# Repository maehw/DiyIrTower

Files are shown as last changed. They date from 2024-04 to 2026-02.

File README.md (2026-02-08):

# README

Can be used as a replacement of the original LEGO IR serial tower with programs and platforms such as

* [WebPBrick](https://www.webpbrick.com): web-based NQC IDE (see also: [github.com/maehw/WebPBrick/](https://github.com/maehw/WebPBrick/))
* [Bricx Command Center (BricxCC)](https://bricxcc.sourceforge.net/): 32-bit Windows IDE
* `firmdl3` command line download tool
* probably other software

to **load user programs and firmware** on the yellow LEGO Mindstorms RCX programmable brick.

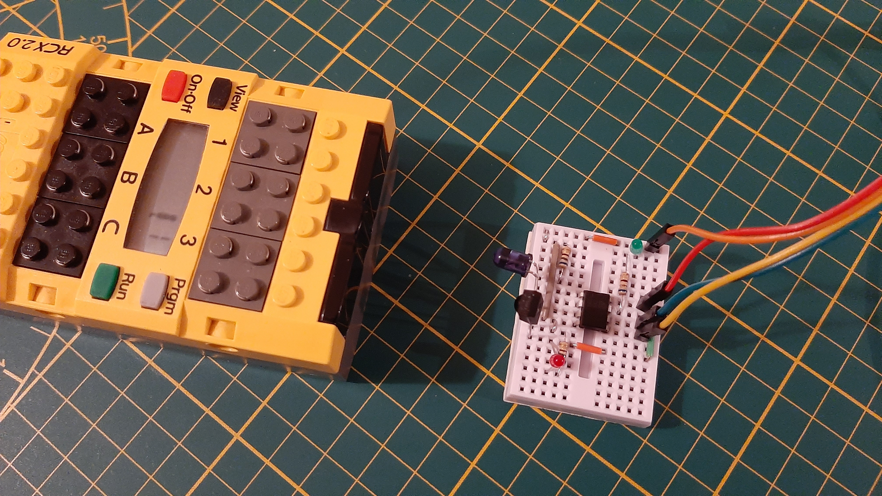
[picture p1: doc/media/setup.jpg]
RCX firmware download setup


## Hardware

> ⚠️ **Warning**: Exposure to infrared light can cause harm to humans. Prolonged or intense exposure may lead to damage to the eyes or skin. Always use proper safety equipment when working with infrared light sources. Make sure to limit the current through the infrared TX LED!

### Pin Assignment

At the heart of the DIY solution, there's an 8-pin ATtiny13A microcontroller.

Pin Assignment Table for the ATtiny13A:

| IC Pin | Pin | Purpose | Direction | Side of IC | ISP Usage |
|---|---|---|---|---|---|
| 1 | PB5 | Reset | Unused | Left | Reset |
| 2 | PB3 | IR_LED_TX_PIN | Output | Left | |
| 3 | PB4 | PHOTO_RX_PIN | Input | Left | |
| 4 | GND | Ground | - | Left | GND |
| 5 | PB0 | UART_RX_PIN | Output | Right | MOSI |
| 6 | PB1 | UART_TX_PIN | Input | Right | MISO |
| 7 | PB2 | IR_ACTIVITY_LED_PIN  | Output | Right | SCK |
| 8 | VCC | Supply Voltage (VCC) | - | Right | VCC |

The column "ISP Usage" shows what pins need to be connected for programming ("flashing") by a 6-pin AVR _In-System Programmer_ (ISP).

### Hardware Parts

- ATtiny13A microcontroller as the "brain" (calibrated internal 9.6 MHz oscillator as clock source; other uCs such as the ATtiny85 _may_ work as they have more SRAM and more flash memory, but timing values will need to be adjusted)
- Vishay Semiconductors TSOP4338 or TSOP4838 38 kHz infrared receiver (others 38 kHz infrared receivers _may_ work)
- Vishay Semiconductors TSAL6200 940 nm infrared TX LED (others 940 nm infrared TX LEDs _may_ work)

If you've built a working DiyIrTower yourself with these or different parts, please let me know! The first design has used the TSOP4338. As it's not available everywhere, it has also been tested to work with the TSOP4838.

In my case, the circuitry is powered by a USB/serial converter cable which is also used to transfer the data over a virtual COM port (USB CDC interface). Please note that the converter cable of choice uses TTL voltage levels and not RS-232!

### Classic Breadboard

For the breadboard version see the image at the top. The Fritzing breadboard diagram looks as follows (please also pay attention to the hints inside the image):

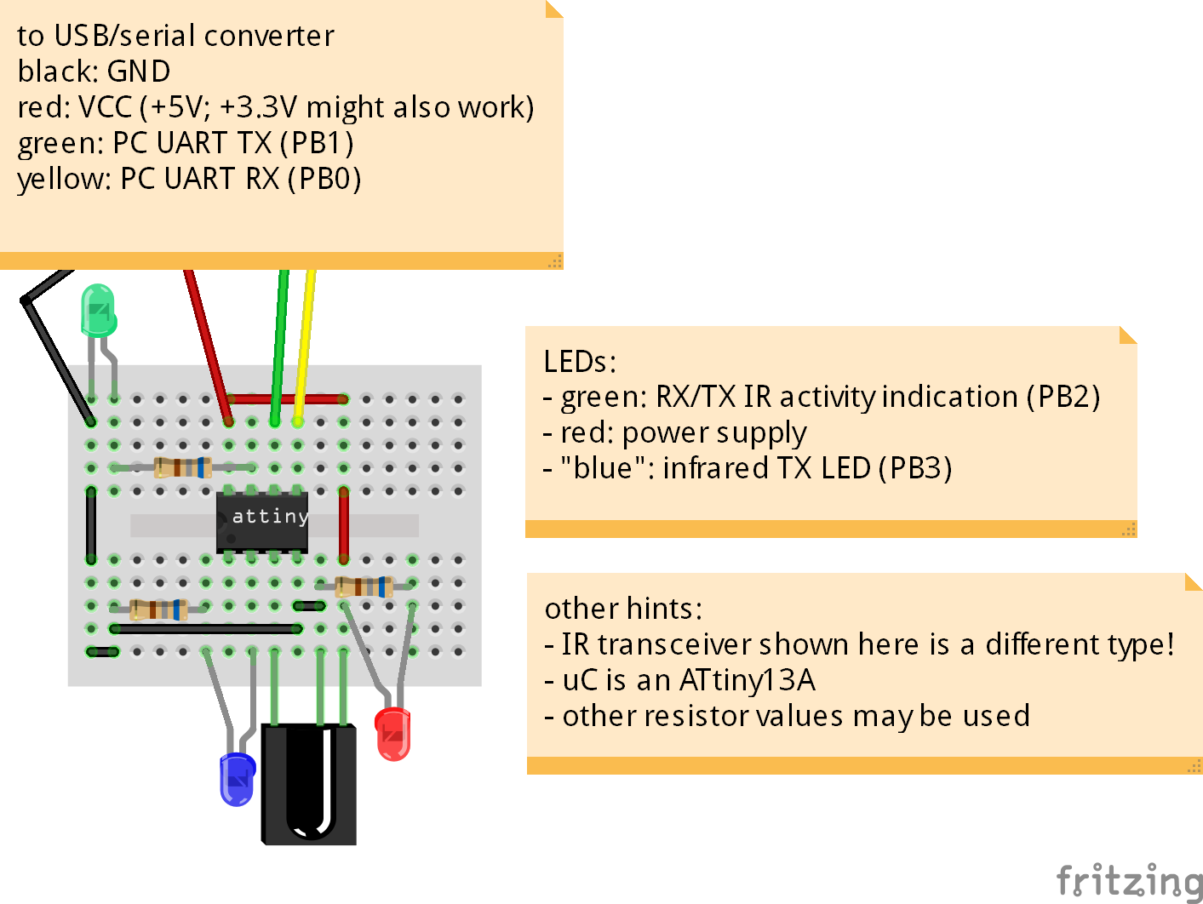
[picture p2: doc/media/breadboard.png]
Fritzing breadboard diagram


### Solder Breadboard

An alternative would be a solder breadboard to make something semi-permanent (the green activity LED is hidden in the next photo between the jumper wires of the USB/serial converter cable):

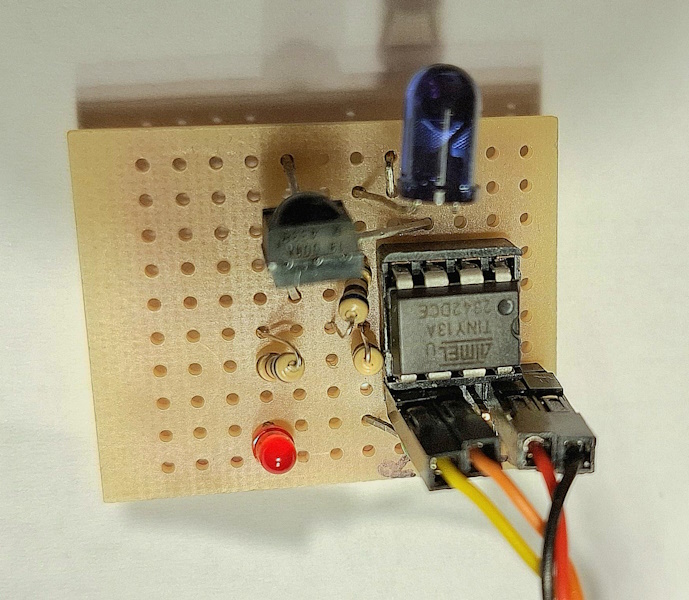
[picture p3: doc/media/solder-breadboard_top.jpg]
Solder breadboard top


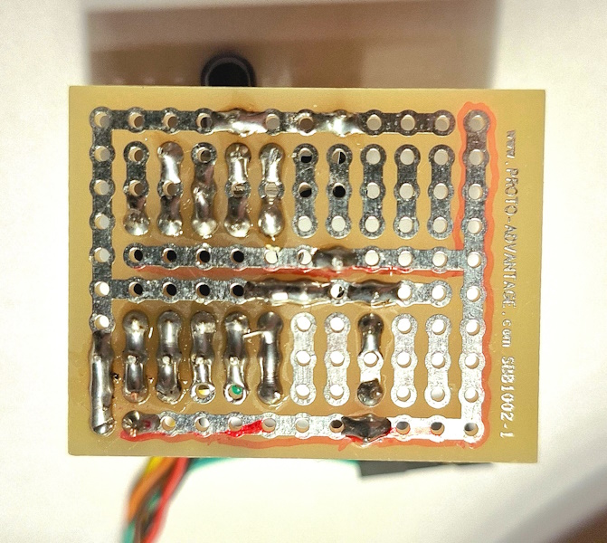
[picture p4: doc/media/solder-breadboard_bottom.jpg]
Solder breadboard bottom


### CAD PCB with KiCAD

Since January 2026, there's a KiCAD project with all necessary files (i.e. schematic, PCB layout, pre-generated Gerber files). So instead of putting the components together on a breadboard, a PCB can be ordered. At the time of writing, some prototype PCBs (Rev. 1.0) have been ordered. But I cannot guarantee, that the design is free of bugs.

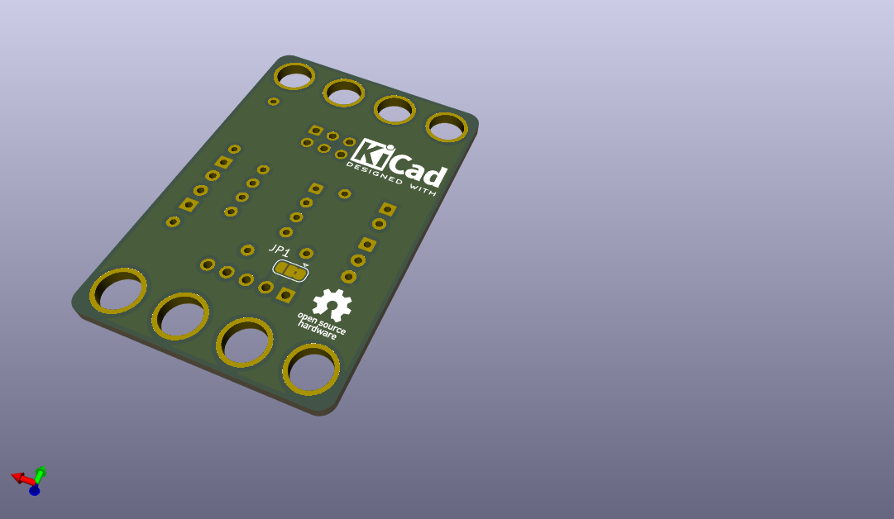
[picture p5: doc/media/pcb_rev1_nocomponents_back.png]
PCB (front) without components


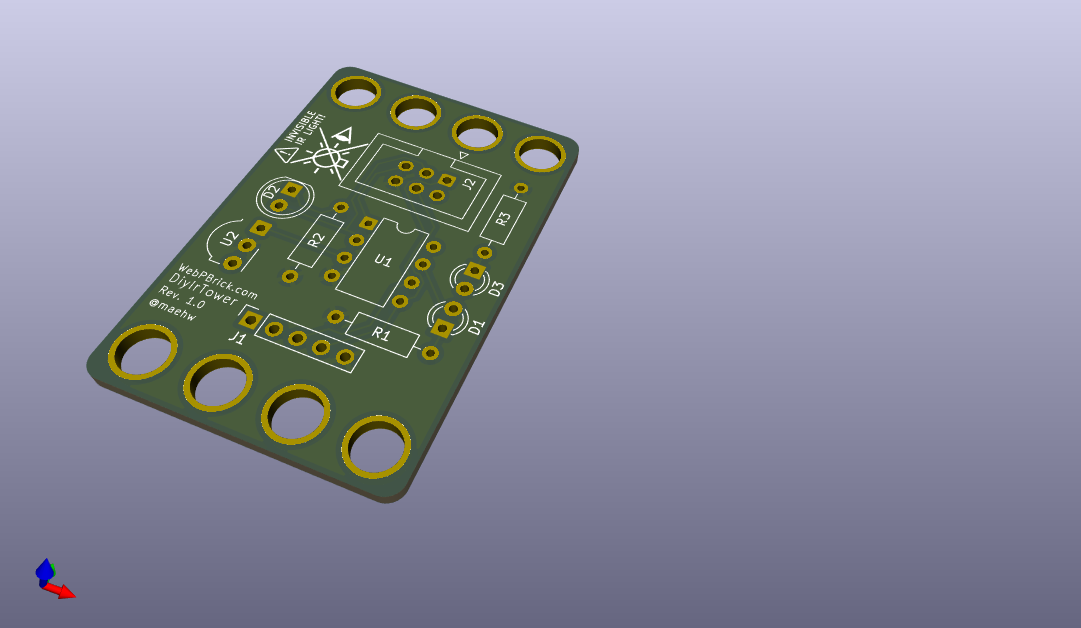
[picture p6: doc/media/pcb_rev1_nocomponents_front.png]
PCB (back) without components


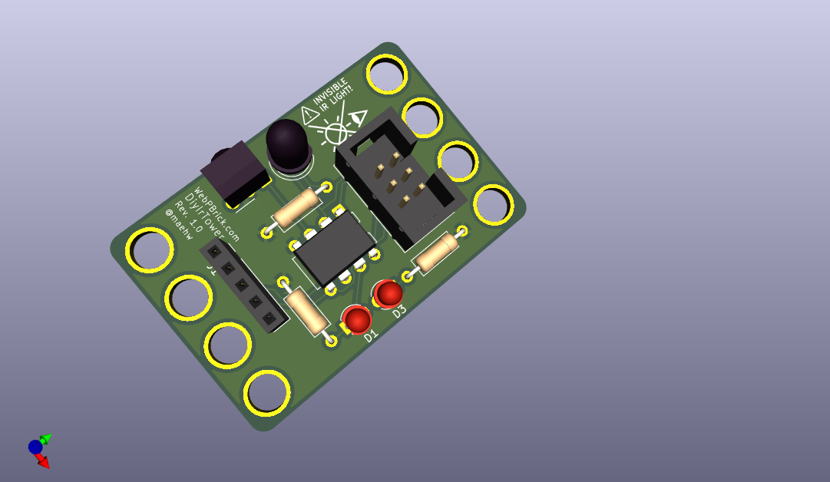
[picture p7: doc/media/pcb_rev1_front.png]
PCB (front) with THT components


I've decided to keep through-hole components, as they are easier to solder for beginners. It may make sense to add a DIP8 IC socket for the uC. The power and activity LEDs (and their resistors) are optional, as is the ISP header for initially flashing the IC. So a setup with the minimum of components would look like this:

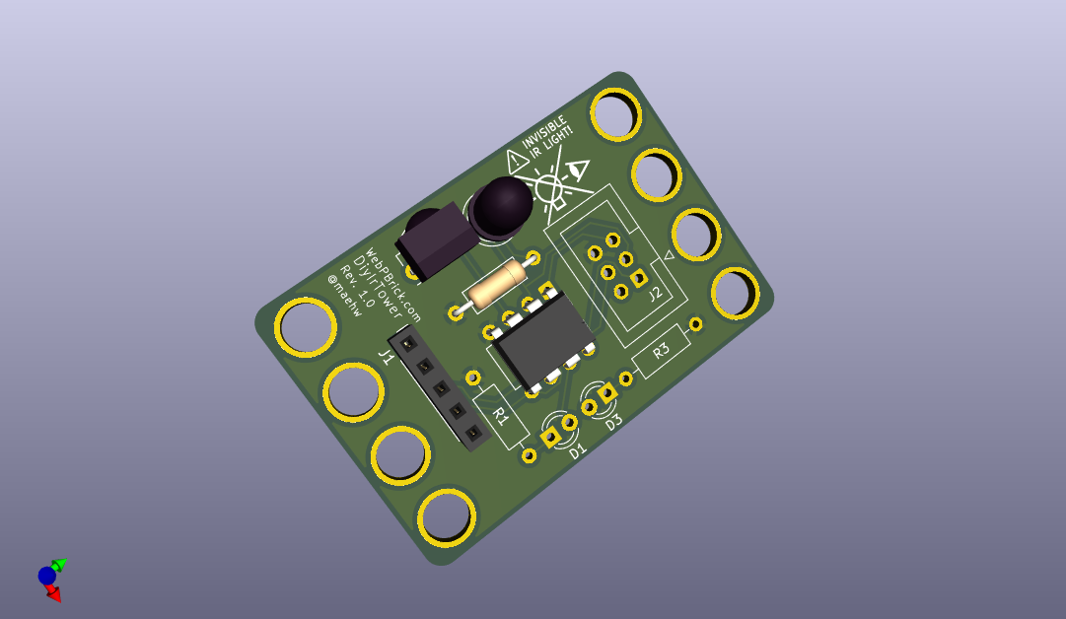
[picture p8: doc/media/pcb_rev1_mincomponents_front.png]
PCB (front) with minimum of THT components


By the way, I'd choose a rectangular connector for J1. Also, you'll have to bend the TX photo diode D2 sideways, so that it points to the same side as the IR receiver IC.

## Firmware

Find the productive firmware in folder `./firmware`.

### Prerequisites

- GNU C cross-compiler for AVR 8-bit `gcc-avr` (other build toolchains *may* work as well)
- `avrdude`: program for downloading and uploading the on-chip memories of AVR microcontrollers (or another similar tool)

### Build

To build, run:

```shell
avr-gcc -g -Wall -Os -mmcu=attiny13a -o main.elf main.c
```

_(Append the verbosity flag `-v` to see what's going on behind the scenes.)_

Want to check if it will it fit into the internal flash?

```shell
avr-size main.elf
   text	   data	    bss	    dec	    hex	filename
    776	      0	      7	    783	    30f	main.elf
```

Make sure to burn the microcontrollers fuses so that

- the calibrated internal 9.6 MHz oscillator is selected
- clock pre-scaler set to 1 (device is shipped with CKDIV8 programmed).

Reading fuses with avrdude (and in this case an `ehajo-isp` in-system programmer):

```shell
avrdude -c ehajo-isp -p t13a -U hfuse:r:-:h -U lfuse:r:-:h
```

The default values for the two fuse bytes of the ATtiny13A are `0xff` (high), `0x6a` (low).  The required settings however are: `0xff` (high), `0x7a` (low). Writing fuses with avrdude:

```shell
avrdude -c ehajo-isp -p t13a -U hfuse:w:0xff:m -U lfuse:w:0x7a:m
```

_(Hint: If the `avrdude` version being used gives *"avrdude: AVR Part "t13a" not found."*, try using `t13` instead of `t13a`.)_

Finally, flash the firmware:

```shell
avrdude -c ehajo-isp -p t13a -U flash:w:main.elf:e
```

### Test firmware

Please note that under `./test/firmware`, there are some more code files to test the assembled hardware. The commands from above can be reused, only the filename needs to be changed.

`blink.c` will blink the activity indication LED and hence allow to check if the LED is working and the compilation and flashing mechanisms also work.

`pulsed_ir_tx.c` will blink the activity indication LED and also transmit modulated infrared light at 38 kHz for 0.5 seconds and then switch the transmitter off for another 0.5 seconds. This allows to check if the fuse bytes have been set correctly or the blinking is way slower and the default `CKDIV8` may not have been overwritten.

`serial_echo.c` will _echo_ the serially received UART characters. Please note that this example does not make use of any uC UART peripheral but only relies upon GPIO pin edge detection on the "UART" receive pin. This can be used with any terminal emulator that works with serial devices or with the Python script `/test/scripts/serial_coms.py` to send and receive binary data:

```shell
$ python serial_coms.py -h
usage: serial_coms.py [-h] serial_device data_to_send

Send binary data over serial and receive response.

positional arguments:
  serial_device  Name of the serial device (e.g., '/dev/ttyUSB0')
  data_to_send   Binary data to send in HEX format (e.g., '55FF00609F609F')

options:
  -h, --help     show this help message and exit
```

Example:

```shell
$ python serial_coms.py /dev/ttyUSB0 11223344
[TX] 11 22 33 44 
[RX] 11 22 33 44
```

The same four bytes should be received that also have been transmitted before - just as you'd expect from an echo application! Check the command line output!

## Design details

The following timing diagram shows four signals from top to bottom:

* `UART_TX_PIN`: the UART transmit (=TX) signal - as sent by the PC, coming from the attached USB/serial converter
* `IR_LED_TX_PIN`: the modulated infrared transmit signal on the IR TX LED, on–off keying (OOK) modulated at 38 kHz, 38 kHz carrier is _active_ during _low_ periods of `UART_TX_PIN`
* `PHOTO_RX_PIN`: the signal on the (already demodulated) infrared receiver
* `UART_RX_PIN`: the UART receive (=RX) signal - as sent by the DIY IR tower to the USB/serial converter

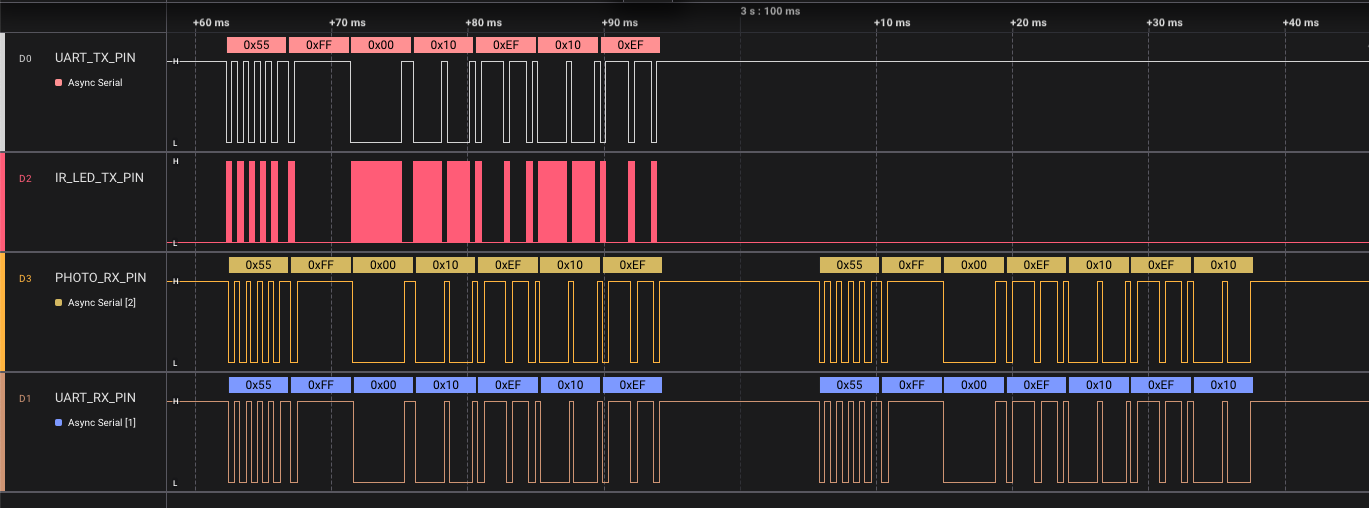
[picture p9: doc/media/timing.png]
Timing diagram


The diagram shows the message `0x55 0xFF 0x00 0x10 0xEF 0x10 0xEF` being sent from the PC to the RCX (left half). It also shows the response from the RCX to the PC: `0x55 0xFF 0x00 0xEF 0x10 0xEF 0x10` (right half).

In the left half one can also see that the signal transmitted by the DIY IR tower is reflected and directly received by itself. This is due to the arrangement of IR TX LED and IR receiver - and afair can also be seen with the original IR towers. This "echo effect" must/can be handled in software!

Zooming in (less time for the same screen width) reveals the delays between the signals:

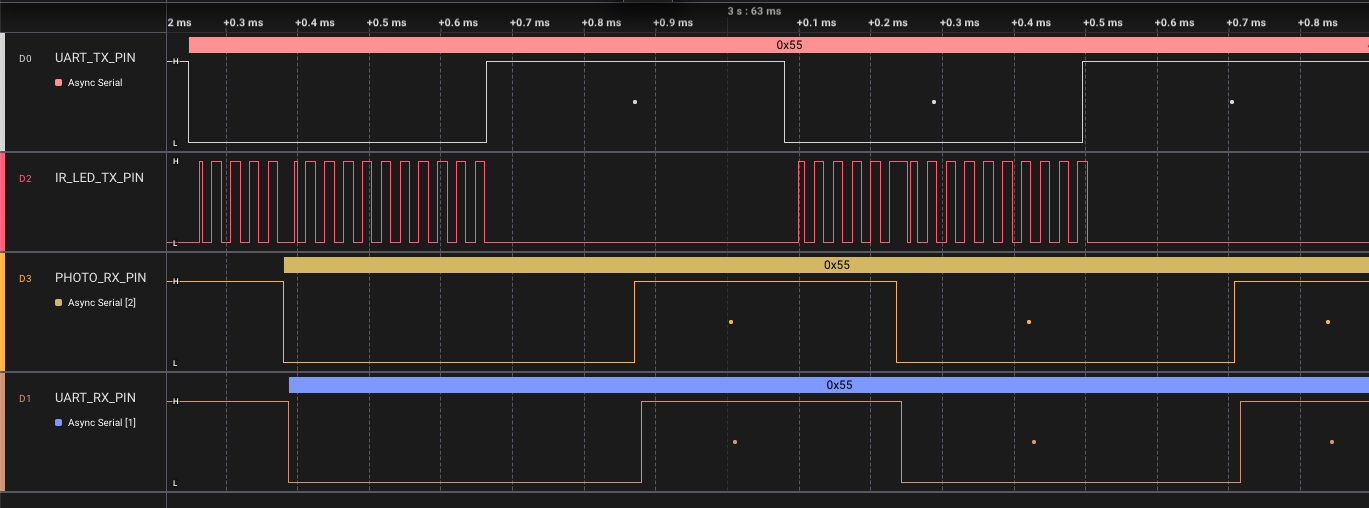
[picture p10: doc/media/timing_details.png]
Timing diagram with details


## Disclaimer

LEGO® is a trademark of the LEGO Group of companies which does not sponsor, authorize or endorse this project.

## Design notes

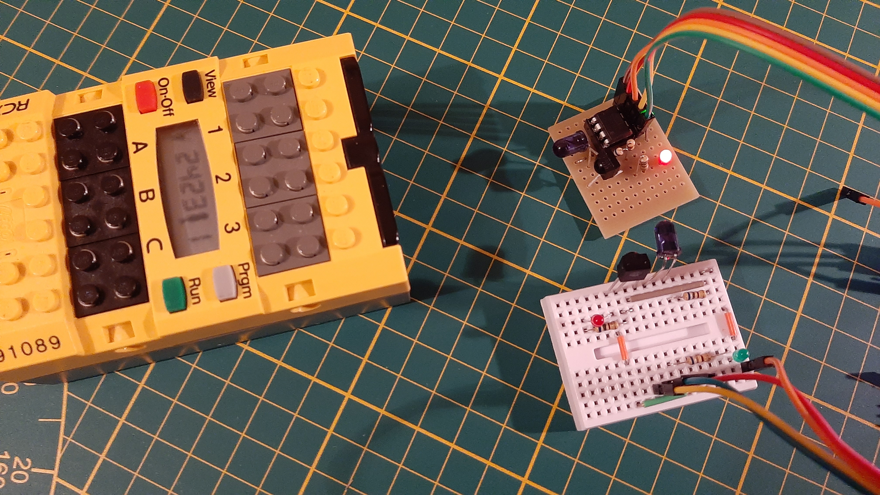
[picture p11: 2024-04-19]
doc/media/firmware-download.jpg

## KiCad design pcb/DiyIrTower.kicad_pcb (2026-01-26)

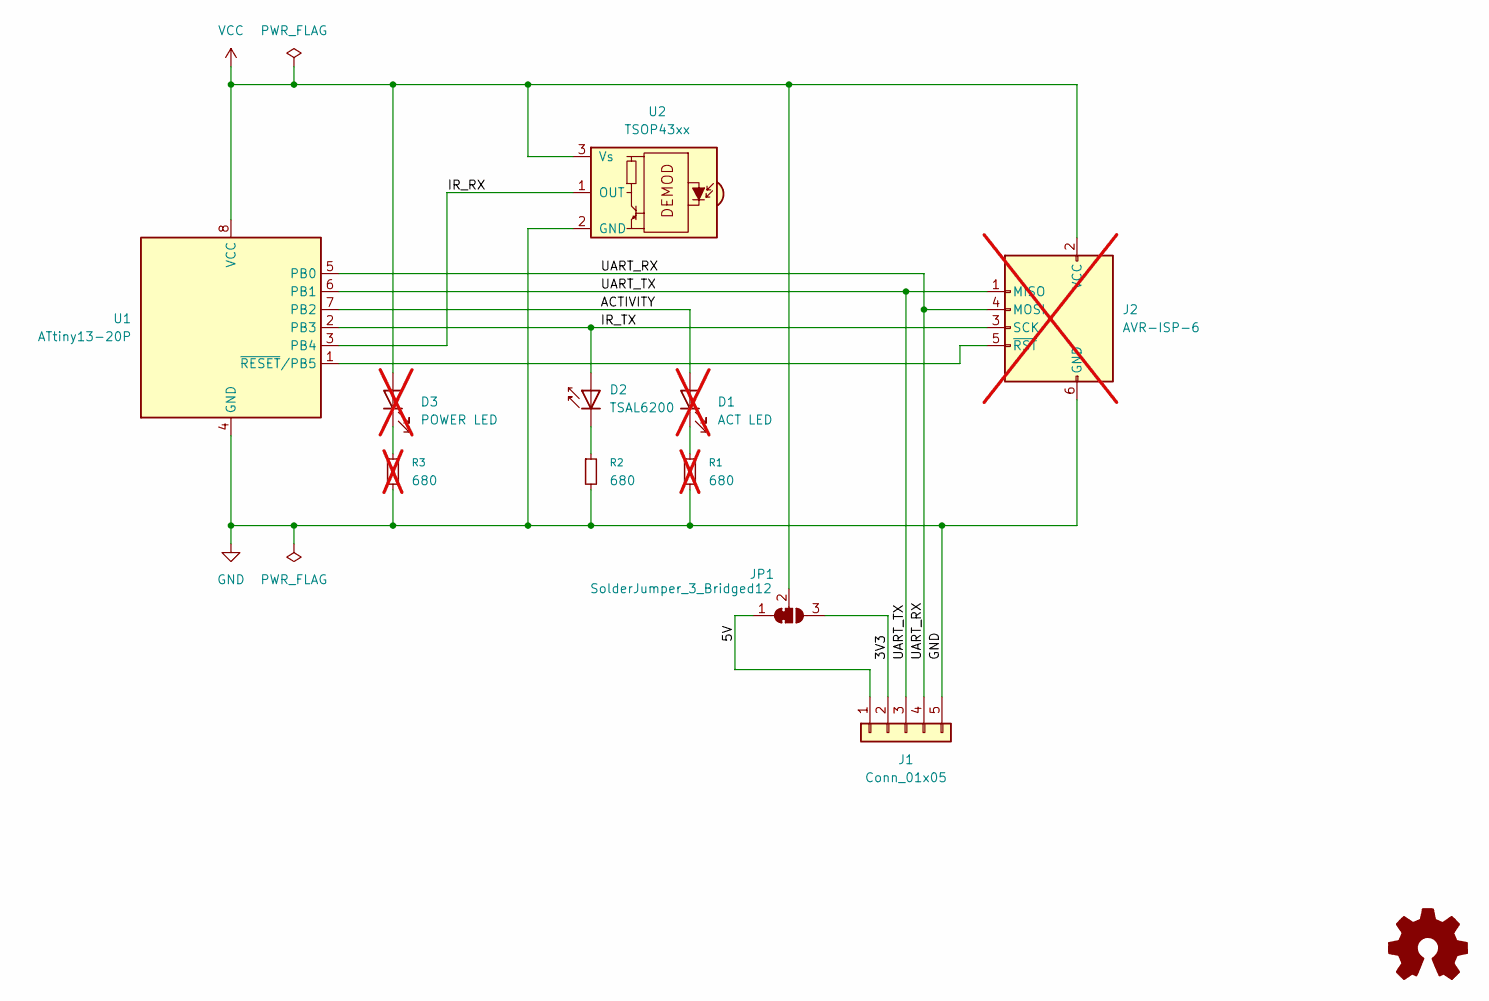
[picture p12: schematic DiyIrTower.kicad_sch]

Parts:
D1: ACT LED; LED_D3.0mm; not fitted
D2: TSAL6200; LED_D5.0mm_IRBlue
D3: POWER LED; LED_D3.0mm; not fitted
J1: Conn_01x05; PinSocket_1x05_P2.54mm_Vertical
J2: AVR-ISP-6; IDC-Header_2x03_P2.54mm_Vertical; not fitted
JP1: SolderJumper_3_Bridged12; SolderJumper-3_P1.3mm_Bridged2Bar12_RoundedPad1.0x1.5mm
R1, R3: 680; R_Axial_DIN0207_L6.3mm_D2.5mm_P10.16mm_Horizontal; not fitted
R2: 680; R_Axial_DIN0207_L6.3mm_D2.5mm_P10.16mm_Horizontal
U1: ATtiny13-20P; DIP-8_W7.62mm
U2: TSOP43xx; Vishay_MOLD-3Pin

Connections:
/3V3: J1.2, JP1.3 (B)
/5V: J1.1, JP1.1 (A)
/ACTIVITY: D1.2 (A), U1.7 (PB2)
/IR_RX: U1.3 (PB4), U2.1 (OUT)
/IR_TX: D2.2 (A), J2.3 (SCK), U1.2 (PB3)
/UART_RX: J1.4, J2.4 (MOSI), U1.5 (PB0)
/UART_TX: J1.3, J2.1 (MISO), U1.6 (PB1)
GND: J1.5, J2.6 (GND), R1.2, R2.2, R3.2, U1.4 (GND), U2.2 (GND)
unnamed: D1.1 (K), R1.1
unnamed: D2.1 (K), R2.1
unnamed: D3.1 (K), R3.1
unnamed: J2.5 (~RST), U1.1 (~RESET/PB5)
VCC: D3.2 (A), J2.2 (VCC), JP1.2 (C), U1.8 (VCC), U2.3 (Vs)

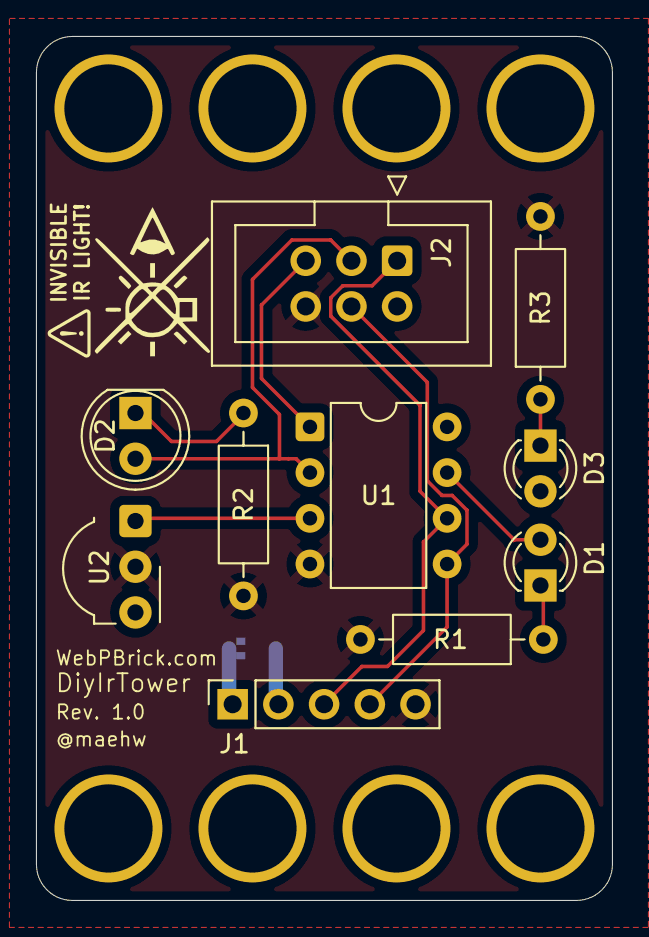
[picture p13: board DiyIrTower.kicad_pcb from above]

Board: 2 copper layers, 32.0 x 48.0 mm, 13 parts (1 on the bottom side), 13 nets.

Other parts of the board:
MH: brick-1x4
MH#2: brick-1x4

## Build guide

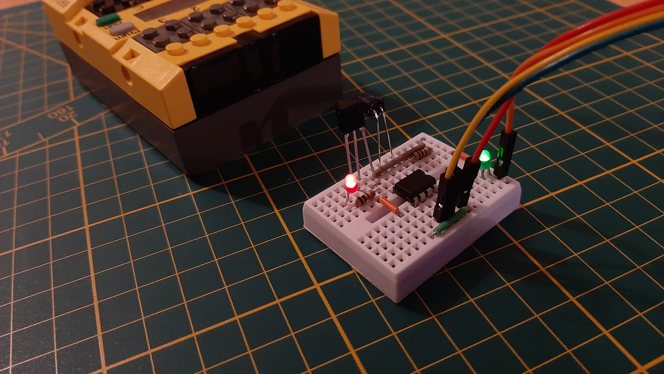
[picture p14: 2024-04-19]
doc/media/setup-side.jpg

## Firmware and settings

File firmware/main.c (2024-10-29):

/*
 * DiyIrTower
 * Copyright (C) 2024 maehw
 *
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
 * You should have received a copy of the GNU General Public License
 * along with this program.  If not, see <http://www.gnu.org/licenses/>.
 */

// This is the productive firmware.

#ifndef F_CPU
    #define F_CPU 9600000UL
#elif F_CPU != 9600000UL
    #error "F_CPU must be set to 9.6 MHz"
#endif

#include <avr/io.h>
#include <avr/interrupt.h>
#include <stdbool.h>

/*
 * Pin Assignment Table for the ATtiny13A:
 *
 * IC Pin | Pin  | Purpose               | Direction | Side of IC
 * --------------------------------------------------------------
 * 1      | PB5  | Reset                 | Unused    | Left
 * 2      | PB3  | IR_LED_TX_PIN         | Output    | Left
 * 3      | PB4  | PHOTO_RX_PIN          | Input     | Left
 * 4      | GND  | Ground                | -         | Left
 * 5      | PB0  | UART_RX_PIN           | Output    | Right
 * 6      | PB1  | UART_TX_PIN           | Input     | Right
 * 7      | PB2  | IR_ACTIVITY_LED_PIN   | Output    | Right
 * 8      | VCC  | Supply Voltage (VCC)  | -         | Right
 */

/*
 * Make sure to burn the fuses so that
 * - the calibrated internal 9.6 MHz oscillator is selected
 * - clock pre-scaler set to 1 (device is shipped with CKDIV8 programmed; which is not what we want).
 *
 * Reading fuses with avrdude (and in this case an ehajo-isp):
 *   avrdude -c ehajo-isp -p t13a -U hfuse:r:-:h -U lfuse:r:-:h
 * The default is: 0xff (high), 0x6a (low)
 *
 * The required setting is: 0xff (high), 0x7a (low)
 * Writing fuses with avrdude:
 *   avrdude -c ehajo-isp -p t13a -U hfuse:w:0xff:m -U lfuse:w:0x7a:m
 *
 * Compile and link it like this:
 *   avr-gcc -g -Wall -Os -mmcu=attiny13a -o main.elf main.c
 * Flash it:
 *   avrdude -c ehajo-isp -p t13a -U flash:w:main.elf:e
 */

#define IR_LED_TX_PIN        PB3 // GPIO output pin for IR LED
#define UART_TX_PIN          PB1 // GPIO input pin for enabling modulation
#define PHOTO_RX_PIN         PB4 // GPIO input pin for the demodulated signal from photo-transistor
#define IR_ACTIVITY_LED_PIN  PB2 // GPIO output pin for indicating IR TX modulation or IR RX signal detection from photo-transistor
#define UART_RX_PIN          PB0 // GPIO output pin that mirrors the input from the photo-transistor

#define MODULATION_FREQ                 38000 // 38 kHz
#define MODULATION_HALF_PERIOD          (F_CPU / (2 * MODULATION_FREQ)) -2 // Calculate the half period in clock cycles; make sure that we really get this to ~2*38 kHz here
// Needed to add a small correction offset determined by measurement:
//  0: 37.5 kHz
// -1: 37.6 kHz
// -2: 38.1 kHz

#define LED_UPDATE_FREQ                 1000 // 1 kHz
#define RX_ACTIVITY_LED_ON_DURATION     160 // Duration in milliseconds for activity status LED to be ON for RX
#define TX_ACTIVITY_LED_ON_DURATION     100 // Duration in milliseconds for activity status LED to be ON for TX

volatile uint8_t modulation_enabled = 0;
volatile uint8_t activity_led_counter = 0;
volatile uint8_t modulation_counter = 0;
volatile uint8_t prev_photo_rx_state = 0;
volatile uint8_t prev_uart_tx_state = 0;

void pin_change(bool on_init);

void setup() {
    // Set IR LED pin, activity status LED pin and UART RX pin as outputs
    DDRB |= (1 << IR_LED_TX_PIN) | (1 << IR_ACTIVITY_LED_PIN) | (1 << UART_RX_PIN);

    // Set enable pin as input
    DDRB &= ~(1 << UART_TX_PIN);

    // Enable internal pull-up resistor for enable pin and photo-transistor input pin
    PORTB |= (1 << UART_TX_PIN) | (1 << PHOTO_RX_PIN);

    // Enable Pin Change Interrupt for PHOTO_RX_PIN (PB4) and UART_TX_PIN (PB1)
    GIMSK |= (1 << PCIE); // Enable Pin Change Interrupt
    PCMSK |= (1 << PCINT4) | (1 << PCINT1); // Enable Pin Change Interrupt on PHOTO_RX_PIN (PB4) and UART_TX_PIN (PB1)

    // Configure Timer0 for 38 kHz modulation frequency
    TCCR0A = (1 << WGM01); // CTC mode
    OCR0A = MODULATION_HALF_PERIOD - 1; // Set the compare value for the desired modulation frequency
    TIMSK0 = (1 << OCIE0A); // Enable Timer0 compare match A interrupt

    // Initialize to correct state
    pin_change(true);

    TCCR0B = (1 << CS00); // Start Timer0 without pre-scaler (i.e. runs with F_CPU)
}

void pin_change(bool on_init) {
    // Get current states of pins PHOTO_RX_PIN and UART_TX_PIN for determining interrupt source and for edge detection
    uint8_t current_photo_rx_state = PINB & (1 << PHOTO_RX_PIN);
    uint8_t current_uart_tx_state = PINB & (1 << UART_TX_PIN);

    if ((current_uart_tx_state != prev_uart_tx_state) || on_init) {
        // UART_TX_PIN state has changed
        if (current_uart_tx_state) {
            // Rising edge detected on UART_TX_PIN

            // Disable modulation
            modulation_enabled = 0;

            // Set IR LED pin to LOW as modulation is disabled
            PORTB &= ~(1 << IR_LED_TX_PIN);
        } else {
            // Falling edge detected on UART_TX_PIN

            // Enable modulation
            modulation_enabled = 1;

            // Re-set duration for activity status LED to be on
            activity_led_counter = (TX_ACTIVITY_LED_ON_DURATION > activity_led_counter) ? TX_ACTIVITY_LED_ON_DURATION : activity_led_counter;

            // Turn on activity status LED
            PORTB |= (1 << IR_ACTIVITY_LED_PIN);
        }

        // Reset modulation counter
        modulation_counter = 0;
    }

    if ((current_photo_rx_state != prev_photo_rx_state) || on_init) {
        // PHOTO_RX_PIN state has changed; it is an active-low signal

        if (current_photo_rx_state) {
            // Rising edge detected on PHOTO_RX_PIN

            // Also set UART_RX_PIN high
            PORTB |= (1 << UART_RX_PIN);
        } else {
            // Falling edge detected on PHOTO_RX_PIN

            // Also set UART_RX_PIN low
            PORTB &= ~(1 << UART_RX_PIN);

            // Re-set duration for activity status LED to be on
            activity_led_counter = (RX_ACTIVITY_LED_ON_DURATION > activity_led_counter) ? RX_ACTIVITY_LED_ON_DURATION : activity_led_counter;

            // Turn on activity status LED
            PORTB |= (1 << IR_ACTIVITY_LED_PIN);
        }
    }

    // Update previous state variables
    prev_photo_rx_state = current_photo_rx_state;
    prev_uart_tx_state = current_uart_tx_state;
}

ISR(PCINT0_vect) {
    pin_change(false);
}

ISR(TIM0_COMPA_vect) {
    // Take care of IR modulation
    if (modulation_enabled) {
        // Toggle IR LED pin every two half periods
        PORTB ^= (1 << IR_LED_TX_PIN);
    }

    // Check if it's time to update LED counters
    static uint8_t led_counter = 0;
    led_counter++;
    if (led_counter >= ((2 * MODULATION_FREQ)/LED_UPDATE_FREQ)) {
        // Reset the counter
        led_counter = 0;

        // Update LED counters: check if activity status LED needs to be switched off again (should be on right now)
        if (activity_led_counter > 0) {
            activity_led_counter--;
            if (activity_led_counter == 0) {
                PORTB &= ~(1 << IR_ACTIVITY_LED_PIN);
            }
        }
    }
}

int main() {
    setup();
    sei(); // Enable global interrupts

    while (1) {
        // Main loop remains idle
    }

    return 0;
}

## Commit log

2024-10-22 Update README.md: add solder breadboard images
2024-10-22 Update README.md: add ISP info to pin assignment
2024-10-22 Update README.md: elaborate on fuse bytes and available test code
2024-10-23 Clean-up UART echo test firmware and documentation
2024-10-29 Fix documentation about fuse bytes; add another example
    [blink.c, main.c, pulsed_ir_tx.c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]
2026-01-26 Add KiCAD 9.0 PCB design and update README.md for it
    [DiyIrTower-B_Cu.gbr, DiyIrTower-B_Mask.gbr, DiyIrTower-B_Silkscreen.gbr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]
2026-01-31 Add license (CERN Open Hardware Licence Version 2 - Weakly Reciprocal) to PCB

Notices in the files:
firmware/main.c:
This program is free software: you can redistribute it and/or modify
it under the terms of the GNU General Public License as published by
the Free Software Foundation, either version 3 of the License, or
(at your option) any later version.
